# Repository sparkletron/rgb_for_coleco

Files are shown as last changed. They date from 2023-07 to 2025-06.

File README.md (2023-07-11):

# RGB for Colecovision
### Schematic and PCB for production of a sub rf replacement board that is Genesis 9 pin compatible.

---

  author: Jay Convertino

  date: 2023.07.10

  details: Converts internal YPbPr to RGB to Pound Genesis cable (Genesis compatible outputs)

  license: MIT

---

## LICENSE
  - All files related to or generated from the KiCAD source fall under the MIT license.
  - All files generated by me, Jay Convertino, fall under the MIT license.
  - All files from other sources fall under the license of their specification.

## RELEASE VERSIONS
### Current
  - 0.5 BETA

### Past
  - DEV

## Intro

  This circuit is a replacment for the sub rf board of the original colecovison.

## SOURCES
### RGB conversion
  - TMS RGB : https://tms-rgb.com/ : Nicholas Piegdon

  Special thanks to Nicholas Piegdon. For using the TI YPbPr chip in his design and coming up with the resistor values to obtain proper color
  balance from a TMS9928. This circuit uses a different method for the too much blue. In this case it switches to a sample generated internally by the coleco that is also used to set the DC offset during sync. Also the driver is based on being compatible with the sega
  genesis. This works well with the Pound cable, yes its kinda crap, but its cheap and provides a baseline from which you can only go up.

## REQUIREMENTS
  - KiCAD v7.X

## BUILD TIPS
  This design is made so anyone can build this. You may send it out to a fab house, you may use a PCB mill, or even etch it.
  This is possible since the components can serve as the plated through hole. Other holes can simply have a solid piece of
  wire inserted and soldered to complete the connection (excess resistor leads is a great option).

  Recommend removing the Y, Pb, Pr inductors that are inline if they are there. They will cause color smearing.

  Output composite resistors and cap are optional, can replace the resistor connecting the output to the inverting input with a jumper.
  If no gain is wanted.

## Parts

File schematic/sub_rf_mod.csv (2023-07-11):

# | Reference | Qty | Value | Footprint | DNP
1 | C1, C2, C3, C4, C5, C6, C11, C12, C19, C20, C21, C22, C23, C28, C29 | 15 | 100nF | Capacitor_THT:C_Disc_D5.0mm_W2.5mm_P5.00mm
2 | C7, C8, C9, C10, C13, C16, C17, C25 | 8 | 10uF | Capacitor_THT:CP_Radial_D4.0mm_P2.00mm
3 | C14, C15 | 2 | 22pF | Capacitor_THT:C_Disc_D5.0mm_W2.5mm_P5.00mm
4 | C18 | 1 | 4.7uF | Capacitor_THT:CP_Radial_D4.0mm_P2.00mm
5 | C24 | 1 | 10uF | Capacitor_THT:CP_Radial_Tantal_D4.5mm_P2.50mm
6 | D1, D2 | 2 | D_Zener | Diode_THT:D_DO-35_SOD27_P7.62mm_Horizontal
7 | H1, H2 | 2 | MountingHole_Pad | MountingHole:MountingHole_2.2mm_M2_DIN965_Pad
8 | H3 | 1 | MountingHole_Pad | MountingHole:MountingHole_3mm_Pad
9 | J1 | 1 | Conn_01x08 | Connector_PinHeader_2.54mm:PinHeader_1x08_P2.54mm_Vertical
10 | J2 | 1 | MD-90SM | KiCad:MD90SM
11 | Q1 | 1 | 2N3906 | Package_TO_SOT_THT:TO-92_Wide
12 | R1 | 1 | 100K | Resistor_THT:R_Axial_DIN0207_L6.3mm_D2.5mm_P7.62mm_Horizontal
13 | R2 | 1 | 5K6 | Resistor_THT:R_Axial_DIN0207_L6.3mm_D2.5mm_P7.62mm_Horizontal
14 | R3, R4, R8 | 3 | 4K7 | Resistor_THT:R_Axial_DIN0207_L6.3mm_D2.5mm_P7.62mm_Horizontal
15 | R5 | 1 | 580k | Resistor_THT:R_Axial_DIN0207_L6.3mm_D2.5mm_P7.62mm_Horizontal
16 | R6, R10 | 2 | 1K | Resistor_THT:R_Axial_DIN0207_L6.3mm_D2.5mm_P7.62mm_Horizontal
17 | R7 | 1 | 1k | Resistor_THT:R_Axial_DIN0207_L6.3mm_D2.5mm_P7.62mm_Horizontal
18 | R9 | 1 | 100R | Resistor_THT:R_Axial_DIN0207_L6.3mm_D2.5mm_P7.62mm_Horizontal
19 | R11 | 1 | 470R | Resistor_THT:R_Axial_DIN0207_L6.3mm_D2.5mm_P7.62mm_Horizontal
20 | R12, R16, R17 | 3 | 910R | Resistor_THT:R_Axial_DIN0207_L6.3mm_D2.5mm_P7.62mm_Horizontal
21 | R13 | 1 | 680R | Resistor_THT:R_Axial_DIN0207_L6.3mm_D2.5mm_P7.62mm_Horizontal
22 | R14 | 1 | 160R | Resistor_THT:R_Axial_DIN0207_L6.3mm_D2.5mm_P7.62mm_Horizontal
23 | R15 | 1 | 620R | Resistor_THT:R_Axial_DIN0207_L6.3mm_D2.5mm_P7.62mm_Horizontal
24 | R18, R19, R21, R22, R25 | 5 | 75R | Resistor_THT:R_Axial_DIN0207_L6.3mm_D2.5mm_P7.62mm_Horizontal
25 | R20 | 1 | 10K | Resistor_THT:R_Axial_DIN0207_L6.3mm_D2.5mm_P10.16mm_Horizontal
26 | R23, R24 | 2 | 330R | Resistor_THT:R_Axial_DIN0207_L6.3mm_D2.5mm_P7.62mm_Horizontal
27 | R26 | 1 | 10R | Resistor_THT:R_Axial_DIN0207_L6.3mm_D2.5mm_P7.62mm_Horizontal
28 | R27 | 1 | 180R | Resistor_THT:R_Axial_DIN0207_L6.3mm_D2.5mm_P7.62mm_Horizontal
29 | U1 | 1 | NE5532 | Package_SO:SOIC-8_3.9x4.9mm_P1.27mm
30 | U2, U7 | 2 | MAX4395ESD | Package_SO:SO-14_3.9x8.65mm_P1.27mm
31 | U3 | 1 | LM1881 | Package_SO:SOIC-8_3.9x4.9mm_P1.27mm
32 | U5 | 1 | ADG453 | Package_SO:SOIC-16_3.9x9.9mm_P1.27mm
33 | U6 | 1 | LMH1251 | Package_SO:TSSOP-24_4.4x7.8mm_P0.65mm
34 | U8 | 1 | L7805 | Package_TO_SOT_THT:TO-220-3_Vertical

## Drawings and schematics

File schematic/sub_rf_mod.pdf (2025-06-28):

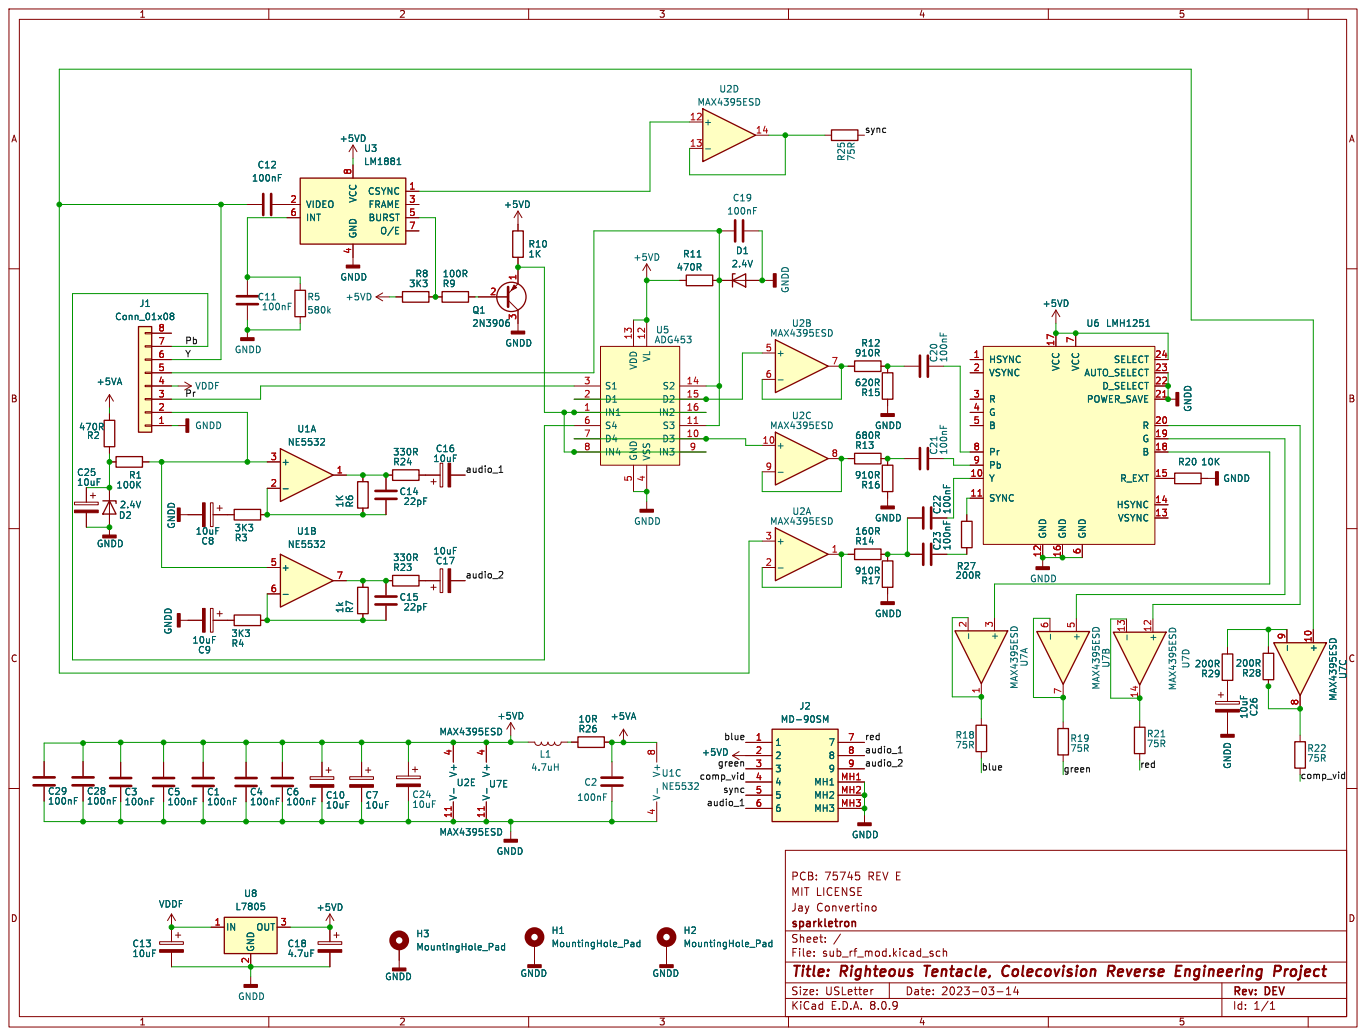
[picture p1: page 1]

Id: 1/1 Title: Righteous Tentacle, Colecovision Reverse Engineering Project File: sub_rf_mod.kicad_sch Sheet: / sparkletron

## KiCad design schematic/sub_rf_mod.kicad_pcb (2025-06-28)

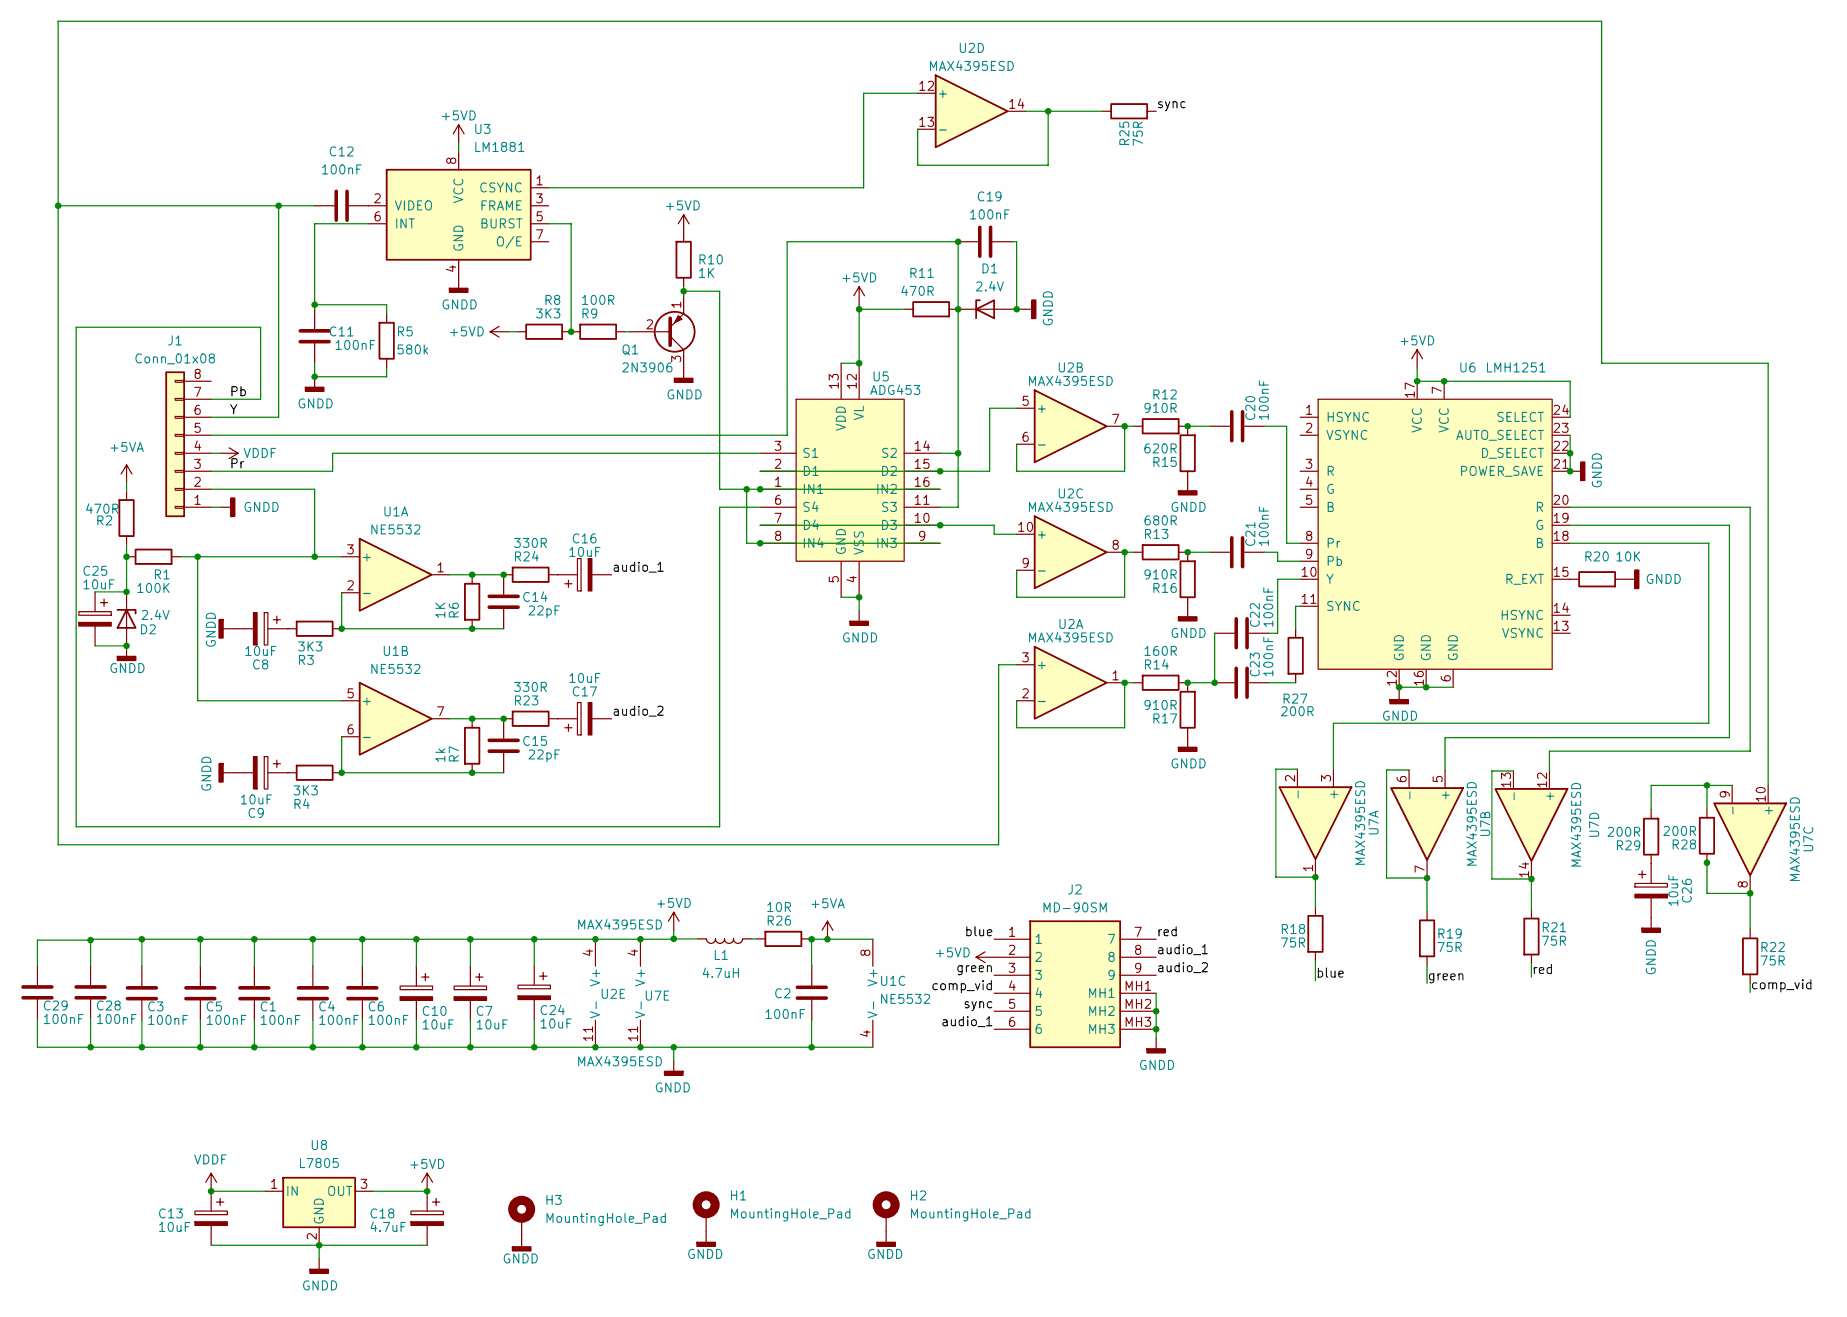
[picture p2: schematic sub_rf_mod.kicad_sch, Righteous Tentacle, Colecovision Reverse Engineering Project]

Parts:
C1, C2, C3, C4, C5, C6, C11, C12, C19, C20, C21, C22, C23, C28, C29: 100nF; C_Disc_D5.0mm_W2.5mm_P5.00mm
C7, C8, C9, C10, C13, C16, C17, C25, C26: 10uF; CP_Radial_D4.0mm_P2.00mm
C14, C15: 22pF; C_Disc_D5.0mm_W2.5mm_P5.00mm
C18: 4.7uF; CP_Radial_D4.0mm_P2.00mm
C24: 10uF; CP_Radial_Tantal_D4.5mm_P2.50mm
D1, D2: 2.4V; D_DO-35_SOD27_P7.62mm_Horizontal
H1, H2: MountingHole_Pad; MountingHole_2.2mm_M2_DIN965_Pad
H3: MountingHole_Pad; MountingHole_3mm_Pad
J1: Conn_01x08; PinHeader_1x08_P2.54mm_Vertical
J2: MD-90SM; MD90SM; Manufacturer_Part_Number MD-90SM; Mouser Part Number 490-MD-90SM
L1: 4.7uH; L_Axial_L7.0mm_D3.3mm_P10.16mm_Horizontal_Fastron_MICC
Q1: 2N3906; TO-92_Wide
R1: 100K; R_Axial_DIN0207_L6.3mm_D2.5mm_P7.62mm_Horizontal
R2, R11: 470R; R_Axial_DIN0207_L6.3mm_D2.5mm_P7.62mm_Horizontal
R3, R4, R8: 3K3; R_Axial_DIN0207_L6.3mm_D2.5mm_P7.62mm_Horizontal
R5: 580k; R_Axial_DIN0207_L6.3mm_D2.5mm_P7.62mm_Horizontal
R6, R10: 1K; R_Axial_DIN0207_L6.3mm_D2.5mm_P7.62mm_Horizontal
R7: 1k; R_Axial_DIN0207_L6.3mm_D2.5mm_P7.62mm_Horizontal
R9: 100R; R_Axial_DIN0207_L6.3mm_D2.5mm_P7.62mm_Horizontal
R12, R16, R17: 910R; R_Axial_DIN0207_L6.3mm_D2.5mm_P7.62mm_Horizontal
R13: 680R; R_Axial_DIN0207_L6.3mm_D2.5mm_P7.62mm_Horizontal
R14: 160R; R_Axial_DIN0207_L6.3mm_D2.5mm_P7.62mm_Horizontal
R15: 620R; R_Axial_DIN0207_L6.3mm_D2.5mm_P7.62mm_Horizontal
R18, R19, R21, R22, R25: 75R; R_Axial_DIN0207_L6.3mm_D2.5mm_P7.62mm_Horizontal
R20: 10K; R_Axial_DIN0207_L6.3mm_D2.5mm_P10.16mm_Horizontal
R23, R24: 330R; R_Axial_DIN0207_L6.3mm_D2.5mm_P7.62mm_Horizontal
R26: 10R; R_Axial_DIN0207_L6.3mm_D2.5mm_P7.62mm_Horizontal
R27, R28, R29: 200R; R_Axial_DIN0207_L6.3mm_D2.5mm_P7.62mm_Horizontal
U1: NE5532; SOIC-8_3.9x4.9mm_P1.27mm
U2, U7: MAX4395ESD; SO-14_3.9x8.65mm_P1.27mm
U3: LM1881; SOIC-8_3.9x4.9mm_P1.27mm
U5: ADG453; SOIC-16_3.9x9.9mm_P1.27mm
U6: LMH1251; TSSOP-24_4.4x7.8mm_P0.65mm
U8: L7805; TO-220-3_Vertical

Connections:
+5VA: C2.2, R2.2, R26.1, U1.8 (V+)
+5VD: C1.2, C3.2, C4.2, C5.2, C6.2, C7.1, C10.1, C18.1, C24.1, C28.2, C29.2, J2.2, L1.2, R8.1, R10.2, R11.1, U2.4 (V+), U3.8 (VCC), U5.12 (VL), U5.13 (VDD), U6.7 (VCC), U6.17 (VCC), U6.24 (SELECT), U7.4 (V+), U8.3 (OUT)
/Pb: J1.7, U5.6 (S4)
/Pr: J1.3, U5.3 (S1)
/Y: C12.1, J1.6, U2.3 (+), U7.10 (+)
/audio_1: C16.2, J2.6, J2.8
/audio_2: C17.2, J2.9
/blue: J2.1, R18.2
/comp_vid: J2.4, R22.2
/green: J2.3, R19.2
/red: J2.7, R21.2
/sync: J2.5, R25.2
GNDD: C1.1, C2.1, C3.1, C4.1, C5.1, C6.1, C7.2, C8.2, C9.2, C10.2, C11.1, C13.2, C18.2, C19.2, C24.2, C25.2, C26.2, C28.1, C29.1, D1.2 (A), D2.2 (A), H1.1, H2.1, H3.1, J1.1, J2.MH1, J2.MH2, J2.MH3, Q1.3 (C), R5.1, R15.1, R16.1, R17.1, R20.2, U1.4 (V-), U2.11 (V-), U3.4 (GND), U5.4 (VSS), U5.5 (GND), U6.6 (GND), U6.12 (GND), U6.16 (GND), U6.21 (POWER_SAVE), U6.22 (D_SELECT), U6.23 (AUTO_SELECT), U7.11 (V-), U8.2 (GND)
unnamed: C8.1, R3.2
unnamed: C9.1, R4.2
unnamed: C14.2, R6.1, R24.2, U1.1
unnamed: C15.2, R7.1, R23.2, U1.7
unnamed: C16.1, R24.1
unnamed: C17.1, R23.1
unnamed: C20.2, R12.2, R15.2
unnamed: C21.2, R13.1, R16.2
unnamed: C22.2, C23.2, R14.1, R17.2
unnamed: C23.1, R27.2
unnamed: C26.1, R29.1
unnamed: C19.1, D1.1 (K), J1.5, R11.2, U5.11 (S3), U5.14 (S2)
unnamed: C25.1, D2.1 (K), R1.1, R2.1
unnamed: J1.2, R1.2, U1.3 (+), U1.5 (+)
unnamed: L1.1, R26.2
unnamed: Q1.2 (B), R9.1
unnamed: Q1.1 (E), R10.1, U5.1 (IN1), U5.8 (IN4), U5.9 (IN3), U5.16 (IN2)
unnamed: R22.1, R28.1, U7.8
unnamed: C14.1, R3.1, R6.2, U1.2 (-)
unnamed: C15.1, R4.1, R7.2, U1.6 (-)
unnamed: R14.2, U2.1, U2.2 (-)
unnamed: U2.5 (+), U5.2 (D1), U5.15 (D2)
unnamed: R12.1, U2.6 (-), U2.7
unnamed: U2.10 (+), U5.7 (D4), U5.10 (D3)
unnamed: R13.2, U2.8, U2.9 (-)
unnamed: U2.12 (+), U3.1 (CSYNC)
unnamed: R25.1, U2.13 (-), U2.14
unnamed: R8.2, R9.2, U3.5 (BURST)
unnamed: C11.2, R5.2, U3.6 (INT)
unnamed: C12.2, U3.2 (VIDEO)
unnamed: C21.1, U6.9 (Pb)
unnamed: C20.1, U6.8 (Pr)
unnamed: R20.1, U6.15 (R_EXT)
unnamed: R27.1, U6.11 (SYNC)
unnamed: C22.1, U6.10 (Y)
unnamed: U6.18 (B), U7.3 (+)
unnamed: R18.1, U7.1, U7.2 (-)
unnamed: U6.19 (G), U7.5 (+)
unnamed: R19.1, U7.6 (-), U7.7
unnamed: R28.2, R29.2, U7.9 (-)
unnamed: U6.20 (R), U7.12 (+)
unnamed: R21.1, U7.13 (-), U7.14
VDDF: C13.1, J1.4, U8.1 (IN)

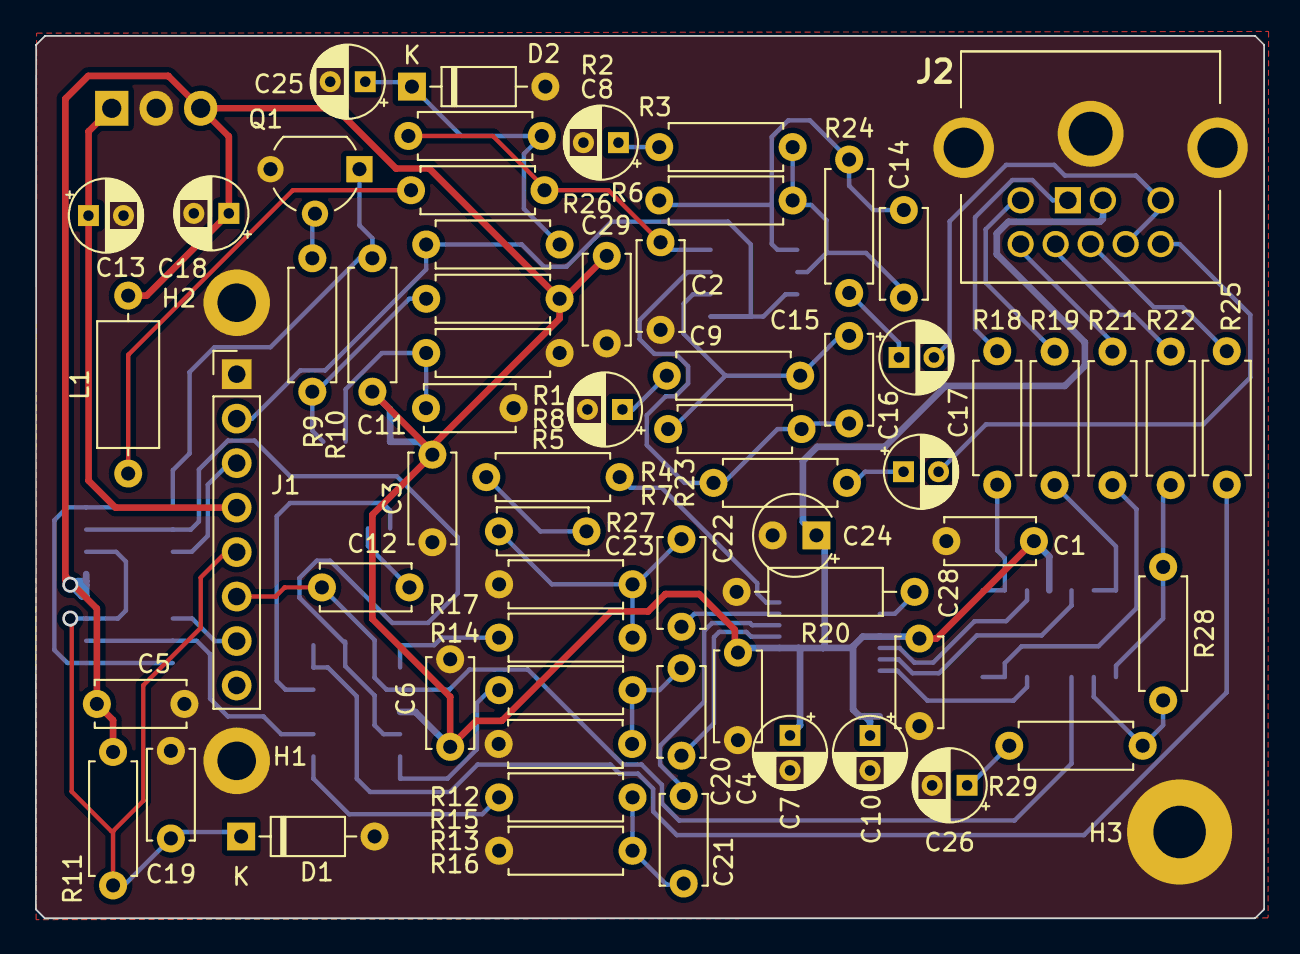
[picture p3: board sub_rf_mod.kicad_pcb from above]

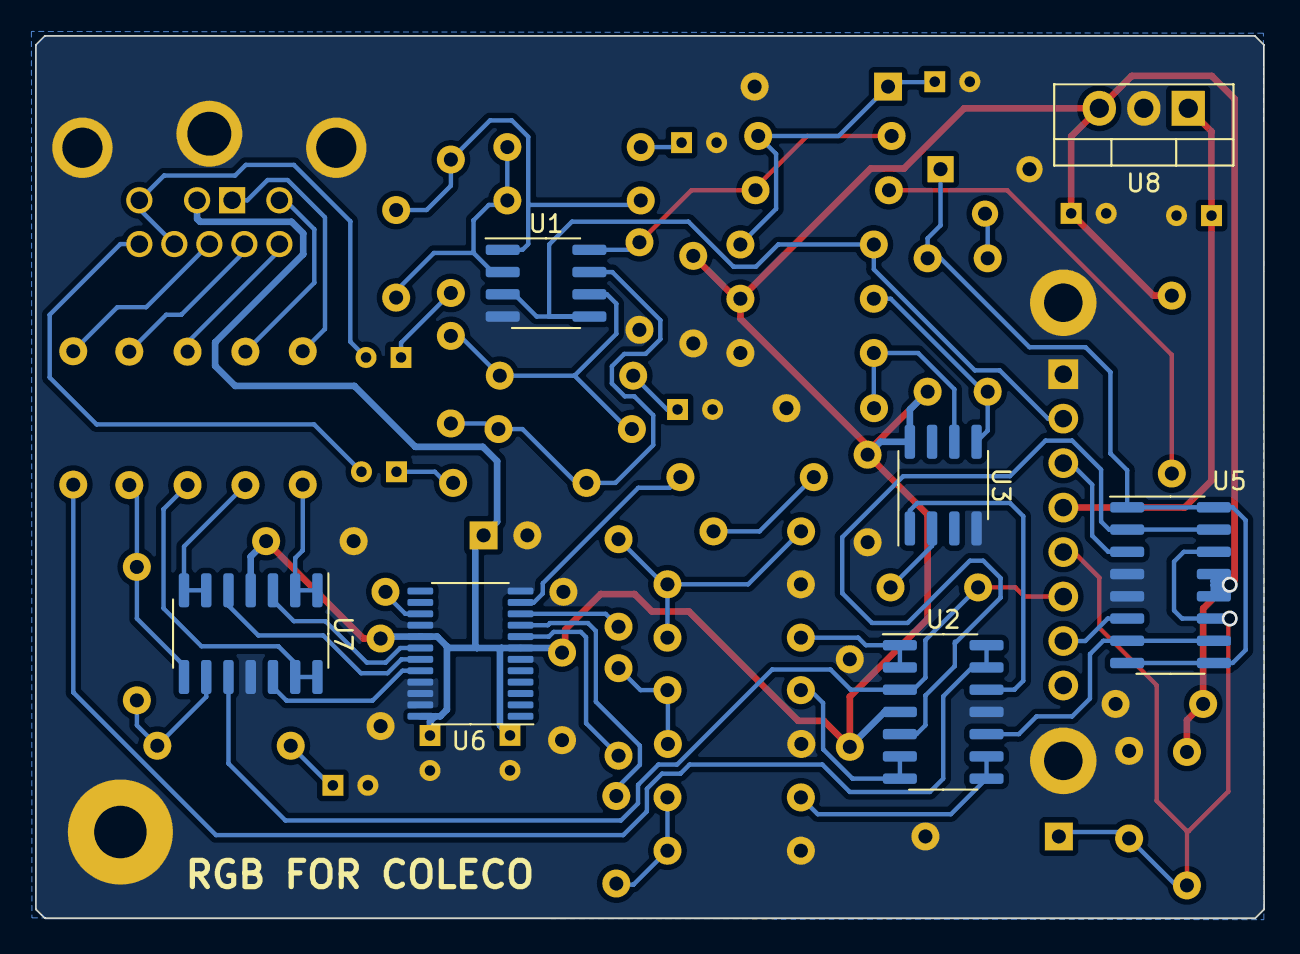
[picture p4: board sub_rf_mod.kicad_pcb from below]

Board: 2 copper layers, 70.1 x 50.4 mm, 73 parts (7 on the bottom side), 56 nets.
